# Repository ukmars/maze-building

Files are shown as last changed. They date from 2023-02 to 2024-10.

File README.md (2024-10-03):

# Building Mazes for Micromouse

For now this repository concerns itself only with the building of a maze for the classic micromouse contest. At some point this will be extended to the half-size contest.

Drawings and STL files for the maze base are in the [resources](./resources/) folder

Drawings and STL files for the walls and posts are in the [walls-and-posts](./walls-and-posts/) folder

These notes are divided into (not very well organised) sections:

- [Goals](./010-Goals.md)
- [Materials](./050-Materials.md)
- [Design](./060-Design.md)
- [Construction](./070-Construction.md)
- [Walls and Posts](./080-Walls-And-Posts.md)
- [Costs](./090-Costs.md)

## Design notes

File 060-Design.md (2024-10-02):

# Design outline

After a lot of deliberation, we settled on a maze constructed from 540mm tiles. Each tile is made from two layers with interlocking tabs to ensure better vertical alignment.

### 540mm Tiles
Increasing the size of the tiless to 540mm x 540mm would mean that 36 tiles are needed to build a full maze although these dimensions are outside the capacity of typical home CNC machines like laser cutters. Tiles this size will fit even in small cars and should be small enough to fit on a car seat and would be small enough to fit within the floor footprint of something like a washing machine. The tiling of these larger pieces allows for a good border around the maze area and no special parts for the outer perimeter walls. The existing UK maze is effectively made up from panels of four 540mm tiles.

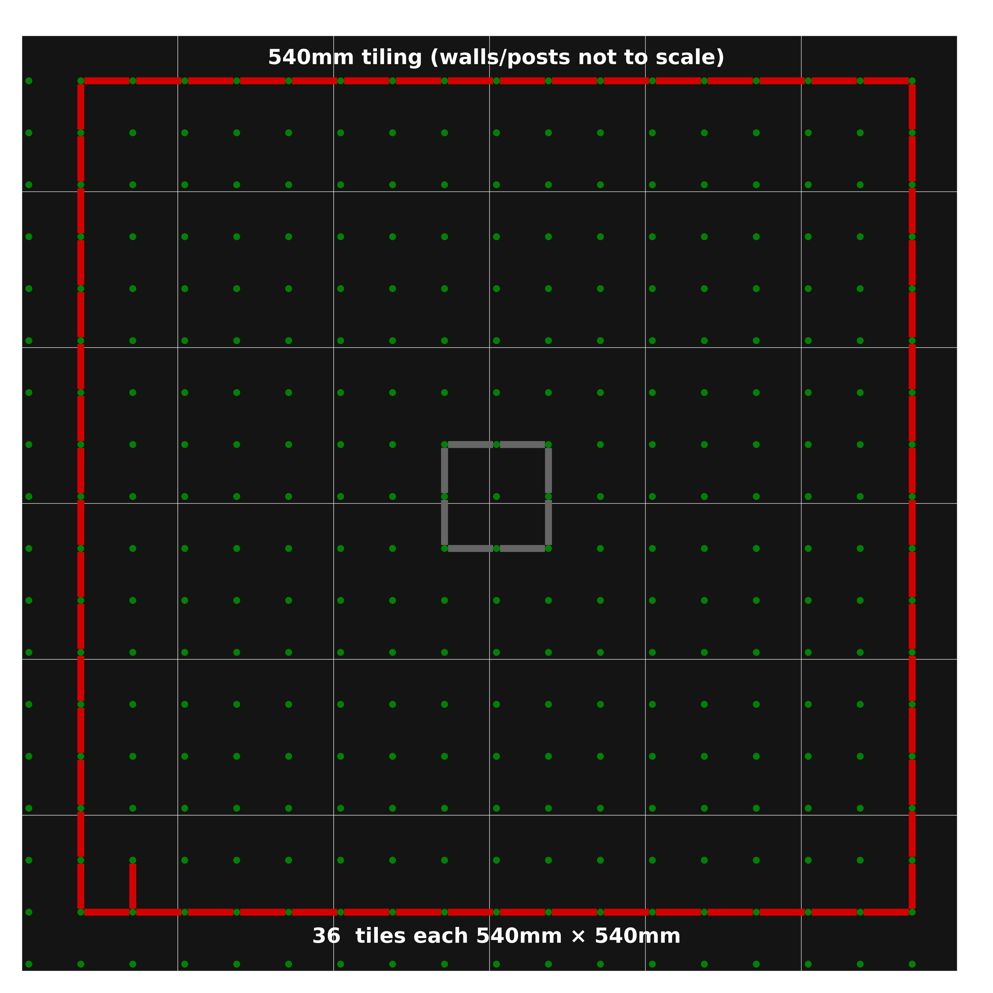
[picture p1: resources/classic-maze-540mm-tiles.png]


The area available is larger than needed for a standard 16x16 maze. The additional space could be used to construct practice areas for sensor calibration.

## Layered Tiles

Regardless of the size of individual tiles they must be joined together somehow. The joins must keep the tiles located both horizontally and vertically with a high degree of accuracy. the published rules permit quite large gaps and steps. This is mostly to remind builders of the worst case. High performance mice are much more sensitive than their forebears from the 1980s and are only really able to shine on a high-quality maze. Thus, a contest maze should be as close to seamless and stepless as possible.

After some experimentation, the final design used in 2023 is a two-layer tabbed tile of 540mmx540mm. Rather than separate tabs, the bottom layer is machined from a single piece to create the interlocking tabs and voids. This view shows a set of four tiles assembled into a panel:

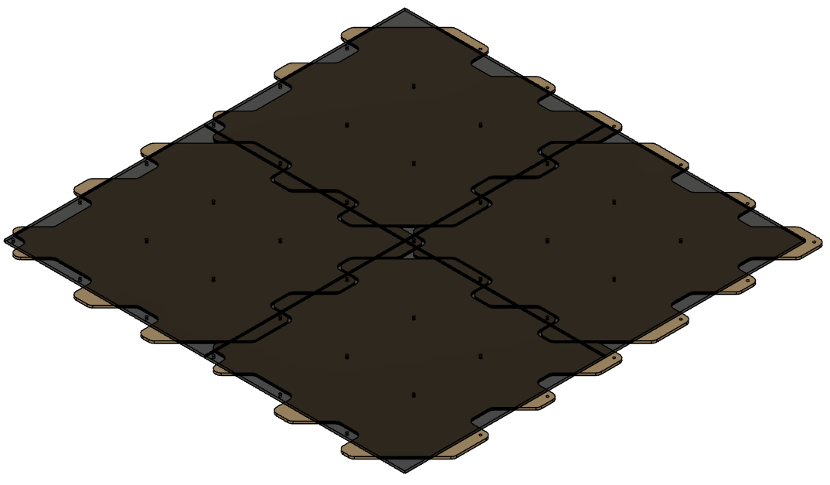
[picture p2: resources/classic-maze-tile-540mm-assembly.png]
540mm-tabbed-assembly


Each tile looks like this and is made of two separate layers aligned by the post holes then glued and pinned together.
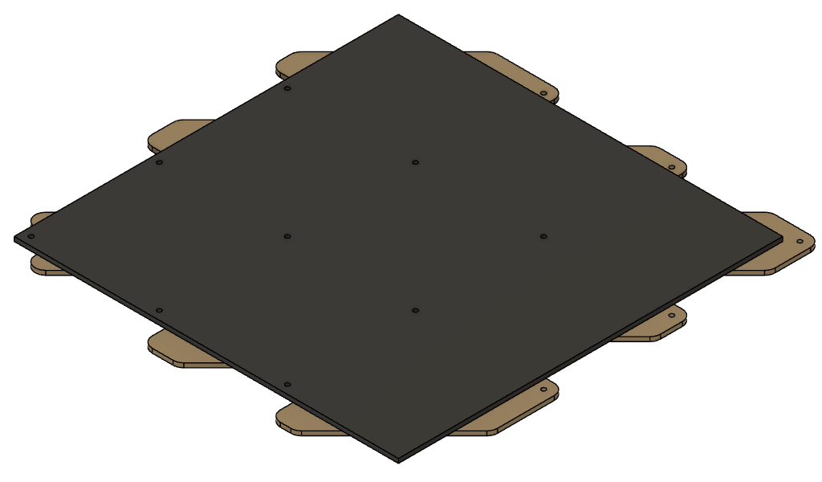
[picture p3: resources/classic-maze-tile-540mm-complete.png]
540mm individual tile


There is a video showing how these are made and assembled:

https://www.youtube.com/watch?v=BzY3Bj1GRg4

## Manufacture

Individual  files showing the component design can be found in the [resources](./resources/) directory. There are images of each part and a PDF file with the dimensions. You will also find DXF and SVG files with the outlines and hole positons. Dimensions are in mm.

The raw material is 6mm MDF. We use self-coloured black MDF but you can use whatever is available and paint it to suit. It is easier to pre-paint the top layer before cutting to avoid having to clean up the holes and edges afterwards.

Holes are nominally 6.1mm and can be adjusted to suit your particular posts.

Cutting the top layer should be done such that it is about 0.25mm undersize to allow for small innaccuracies in the alignment while not creating an excessive gap.

## Edges

In an assembled maze, there will be a row of post holes along two edges that are slightly difficult to use. To make that easier, I have pieces made from two layers of 3mm MDF, cut on a lser. They join together to make a strip like this:

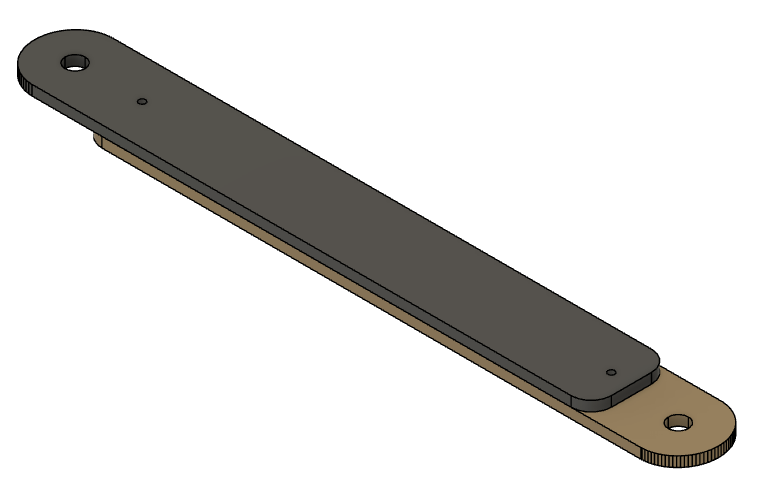
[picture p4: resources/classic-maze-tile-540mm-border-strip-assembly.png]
edge strip


And they can be placed around the edge like this:

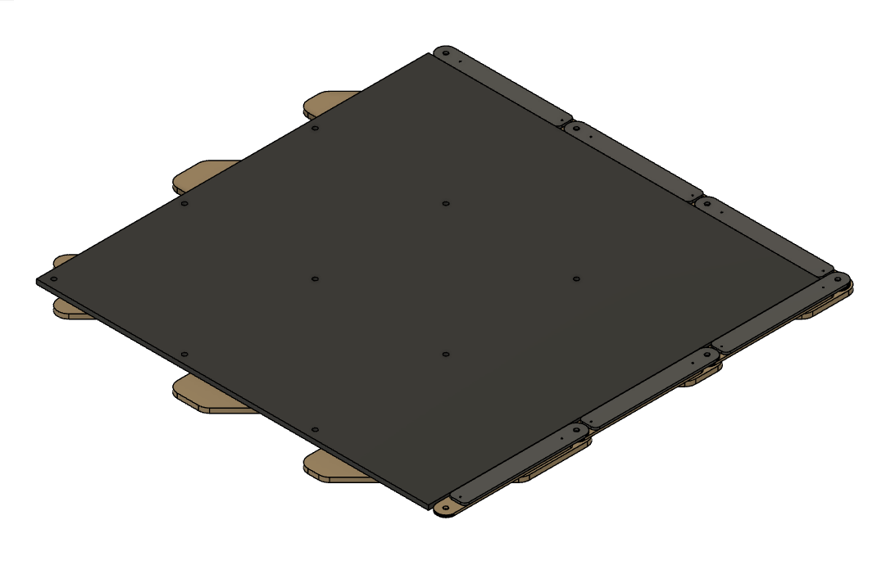
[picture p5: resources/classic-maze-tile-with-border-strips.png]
maze with strips


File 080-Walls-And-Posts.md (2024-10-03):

# Maze Walls and posts

## Walls

Although walls can be 3D printed, the UKMARS contest walls are all made from MDF. Suitable blanks are constructed and then covered with self-adhesive vinyl. The red top is created by adding red masking tape. These materials adhere well enough for contest use and provide a uniform and repeatable surface for sensor calibration.

Each wall has tabs at either end to locate in slots in the posts. Tabs are made from 2mm plywood and glued into slots cut in the wall ends. Any common wood glue will be fine. Do not use the dark brown Gorilla Glue as it expands while curing. The tabs are symmetric to make it easy to insert a wall either way up. With a different bottom surface, walls can easily be inverted to mark off special sections or temporary walls. This is particularly useful when creating a wall-follower maze that is then converted to a normal maze-solver version.

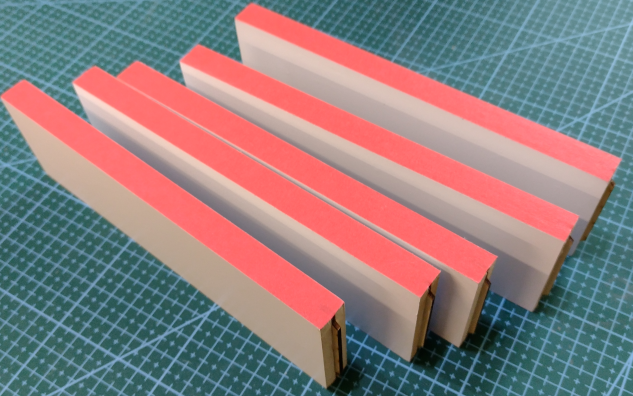
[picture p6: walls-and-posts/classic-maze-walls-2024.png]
Classic Walls


It is possible to make 3D printed walls with an FDM printer. Simply printing the STL file however will be pretty slow. A better solution is modify the slicer settings to use only two outer wall loops, 3 or 4 bottom layers, no top layers and no infill. You can use a relatively large layer height of 0.24mm or more. This creates a hollow wall that can be filled with two pieces of 5mm foamboard for a lightweight and strong wall. The wall should be covered with white self-adhesive vinyl in the same way that the MDF walls are. It may be necessary to add glue to the inside of the walls to prevent them from bowing out around the foamboard filler. Most common glue types will be fine. Hold the walls together while it sets. Do not use the dark brown Gorilla Glue as it expands while curing. 

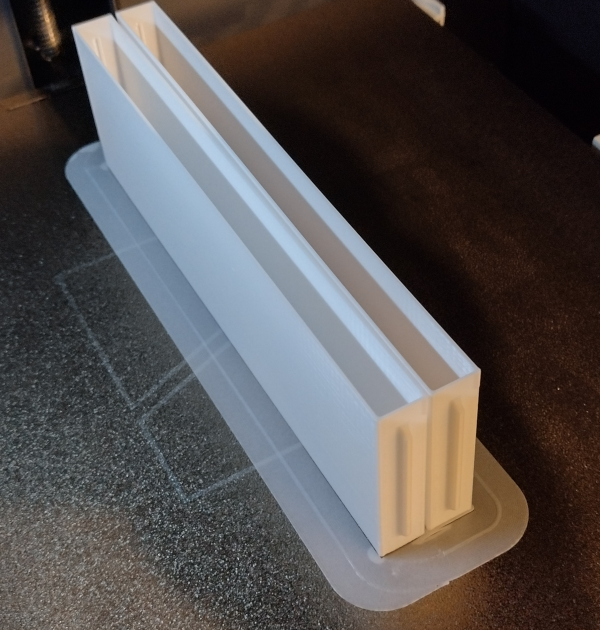
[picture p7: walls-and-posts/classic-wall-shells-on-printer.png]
Classic Wall Shelld and Filled

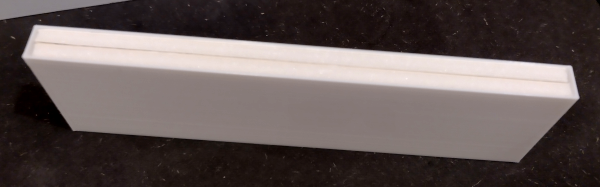
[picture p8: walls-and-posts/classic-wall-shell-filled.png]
Classic Wall Shelled


If you have a fancy multi-filament printer, you can even print the bottom two layers with a red filament.

In the [walls-and-posts](walls-and-posts) folder, there is a .3mf file showing how to set up the slicing.

Note that the walls are a little under the 168mm available between posts. That should ensure some tolerance in manufature. If you make walls, be sure they are no longer than 168mm or there will be problems with the fit.

For a full contest maze there will be a need for some 300 each posts and walls.

The covering material is Ri-Mark Event M300 Matt White Vinyl and is available from many sources. A 5M x 310mm roll would cost about £10 and is enough for about 60 walls.

## Resources
Drawings, descriptions and STL files are available in the [walls-and-posts](walls-and-posts) folder.

## Posts

Maze posts must have slots that provide an easy sliding fit for the tabs on the ends of the walls. The design files here show a post that is 11.5mm square - slightly less than the nominal 12mm square. Like the walls, this provides for some small variation in manufacture ad maze hole positioning. These are quite tight tolerances. If you make yuour own posts, run tests until you are sure you have the sizing correct. It is common for exposure times to affect the finished dimensions of resin prints and the slicer settings will affect the finished size of FDM prints. 

The peg that locates the post, and aligns the maze base parts is nominally 6mm diameter and long enough to fit through two 6mm layers. the peg is shown at less than 6mm in the notes and drawing because misalignment of FDM printed parts will inevitably make the peg seem too tight. Some filing or sanding may be needed to get a good fit. No real harm is done if the posts are a little loose but you will soon tire of having the post pull out whenever you remove a wall.

Posts are relatively hard to make without a 3D printer of some kind. Resin printers are fast (perhaps 30 posts in 2 hours) but the material is brittle. FDM printers are slow (perhaps 8 posts in 4 hours) but the result is much tougher.

There are two post designs in [walls-and-posts](walls-and-posts)

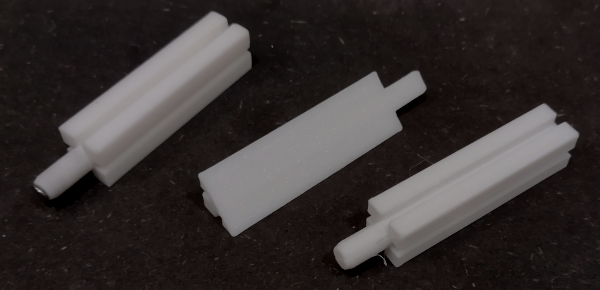
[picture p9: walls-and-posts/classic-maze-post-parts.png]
Classic Post Parts


### Resin printing
For resin printed posts the design incorporates a slightly shorter post with a hole through the centre to accept a 25mmx2mm nail. Nails are glued in to the hole and provide significant reinforcement. Even if a post breaks in the maze, it will be easy to extract the stub. The nails are cheap and readily available. Use an ABS-like white resin. It probably does not matter too much which brand and reflectifity of the posts is not normally a great problem.

### FDM printing
Attemmpting to print the post with an FDM printer as a single piece is doomed. The layers are not strongly bonded and you will get a weak post. The design here prints each post in two halves that are simply glued together to make a full post. Simple superglue is fine but arguably the best choice is the kind og glue sold as 'mitre adhesive' It is quite thick and has a very low odour. Normally it is supplied with a can of accelerant. You can appluy the glue to one half and accelerant to the other. Take care as the accelerant makes it set up almost immediately. I find it better to spray a bit of accelerant on a cloth then wipe the non-glued post half on that to transfer just enough to speed up the setting. The best choice of filament is probably white PETG for toughness and no fumes. However, PLA is cheaper and faster to print. Filament pigmentation can vary greatly. I just use cheap white Geeetech PLA. Many others will work just fine.

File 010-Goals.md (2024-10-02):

# Goals

- create a portable maze for classic micromouse contests
- use multiple identical tiles or panels (a panel is a maze section comprised of one or more tiles)
- limit panel size to no more than 750mm x 750mm
- design for distributed manufacture
- permits full 16x16 maze layout
- panels should be self-aligning vertically and positively located horizontally
- costs should be a significant factor in any choices

To get the question of cost addressed quickly, I estimate that even with economic materials, it may cost something like £45-50 per square meter to build a classic maze which amounts to £350-400 for the whole maze. This is for raw materials only. And relatively cheap ones at that. 

#### Traditional designs

The common approach for a classic micromouse maze is nine sections of around 1m² size. These are typically not all the same design and so must be fitted together in a particular fashion. These sections are large and heavy and do not fit in many family cars. The contest mazes in Japan and Taiwan and the APEC maze are made like this.

#### Tiles and Panels

For a new maze building project UKMARS have used a more flexible design that uses smaller panels. Those panels are large enough that fitting them together is not overly time consuming and yet small enough for easy transport in almost any domestic motor car. Individual panels are light yet durable since they are likely to be poorly handled during transport and storage. All the panels are identical so that they may be assembled with little complication and so that sub-sets may be assembled into custom layouts for special purposes and practice sessions.

#### Distributed Storage

Since the storage and transport of a maze by a single individual or organisation represents a single point of failure, we have made it possible for several members to hold a number of panels so that there is the best possible chance of a complete maze being available at any event. In the worst case, a smaller maze could still be assembled using however many panels are available on the day.

There are currently 6 maze holders, each having ten tiles. Four individuals are needed to make a standard maze and even if only three turn up, a 'legal' classic maze can still be constructed. The 'spare' sections would make an excellent practice maze.

#### Distributed Manufacture

For consistency, all maze tiles were manufactured together on the same CNC machine. Further efforts are underway to help others make dimensionally accurate, compatible tiles without the need for sohisticated machinery.

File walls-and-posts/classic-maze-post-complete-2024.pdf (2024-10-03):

Dept. Technical reference Created by Approved by Title DWG No. Document type Document status Rev. Date of issue Sheet 26/09/2024 1/1 Peter Harrison walls between them 12mm across or there will be problems fitting the The main part of the posts must not be more than the fit will be poor. 6mm and should not be much less than 5.9mm or test posts. The peg diameter must not exceed depend in part on the exposure time. Print some The finished size of your resin printed post will diameter. across the faces and have pegs that are 5.95mm These posts are nominally 11.5mm nominally DIMENSIONS enough to extract from the base. hand. Even if you break the post, it should be easy Glue the nail in with CA glue or whatever comes to the walls. elephant's foot issue whicc can cause interference with The chamfer at the top should help prevent the the hole before final curing. resin to drain out during printing. Be sure to clean out A pair of cross-holes near the top of the post allows nail shaft diameter is about 2mm. nails are very inexpensive. Try some to make surethe is a little shorter to make up for the nail head. These through the peg to accept a common 2mm nail. The peg Since resin prints are fragile, this design has a hole A complete post can be resin 3D printed in one piece. RESIN PRINTED 2.4 2.78

11.5

5.95 50 10.5

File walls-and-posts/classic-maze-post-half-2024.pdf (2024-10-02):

Dept. | Technical reference | Created by | Approved by Document type | Document status Title | DWG No. Rev. | Date of issue | Sheet 26/09/2024 | 1/1 Peter Harrison ⁵⁰ | 11

R2.9

2.75

2.4 MANUFACTURE Posts are typically 3D printed in half pieces. ABS or PETG is preferred for its strength. PLA will work but is more brittle. With a 0.4mm nozzle, on a Bambu P1S, each complete post will take about 8-9 minutes with a 0.24mm layer height. Use 6 walls loops to get a solid post. Fewer for a faster print. DIMENSIONS Each piece is one half of a post with the overall outer dimension set to 11.5mm Test your assembled parts. They must finish at less than 12mm across the flats to ensure that tolerances are met. The peg is shown at 5.8mm diameter. This is less than the nominal 6mm but it turns out to be hard to get perfect alignment when gluing the parts together. Also, your slicer settings and layer height will affect the finshed overall diameter and fit. Make test prints. There is a slight chamfer on the corners to help mitigate the tendency for some printers to produce a bulge at corners. ASSEMBLY Glue two pieces together to make one post. If you use a fast-setting adhesive like CyanoAcrylate, you may find they bond very quickly. It may take a bit of practice to get the alignment correct quickly enough. Some plastics like PETG do not seem to make CA glue cure very quickly. Use a medium thickness CA glue. The type sold in DIY stores as Mitre Adhesive works well. If you use an accelerator, it will greatly speed up the process. For ABS, you can try solvent adhesives which are more forgiving but may require the parts to be held together for some time whyile the glue set up. Consider a grid of 6mm holes in a piece of scrap material 1.5

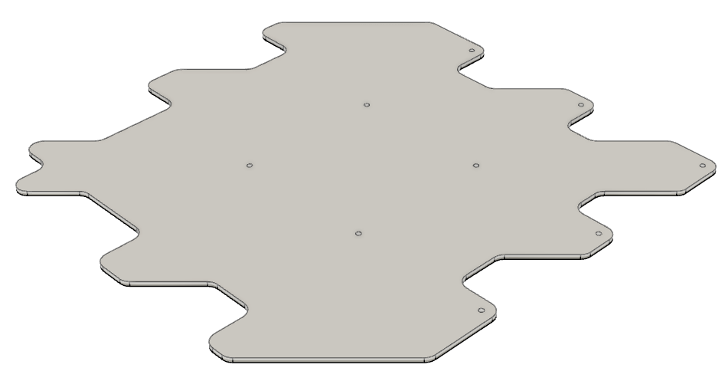
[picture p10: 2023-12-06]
resources/classic-maze-tile-540mm-bottom-layer.png

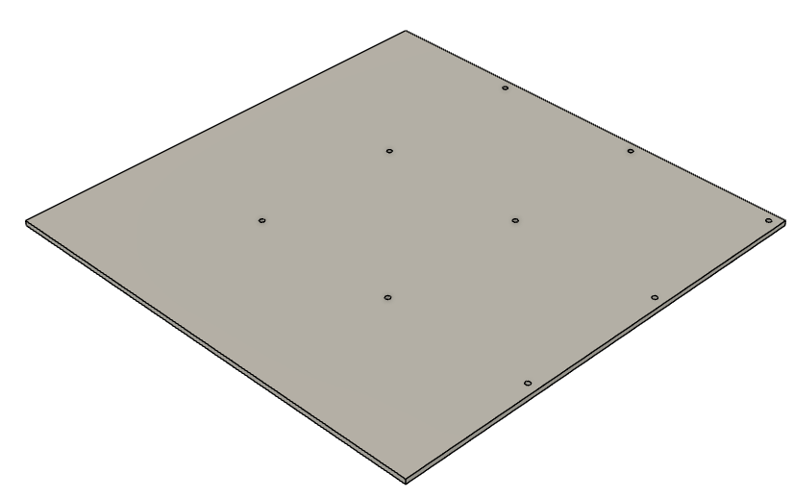
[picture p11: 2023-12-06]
resources/classic-maze-tile-540mm-top-layer.png

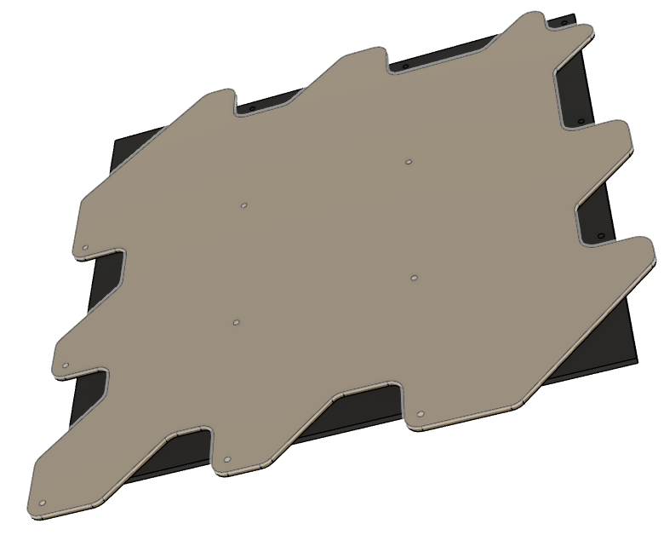
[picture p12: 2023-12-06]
resources/classic-maze-tile-540mm-below.png

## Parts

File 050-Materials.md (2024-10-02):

# Materials

For the current contest maze, UKMARS is using the black-dyed MDF sheet from Kitronic. 

---

For future reference though, here is a brief consideration of some other material choices.

Practically speaking there are few choices of material for the base (prices have been taken from a single supplier and so are only a relative guide, not absolute). Note that layered designs are not absolutely required to use the same material for all layers though there is some risk of differential expansion.

- **Plywood**. Typically 5.5mm thick and avaialble usually with a very thin hardwood veneer. This is lighter than MDF and more resistant to moisture and impact on fine edges. It is also perhaps less likely to be flat across a whole sheet. Varies a lot by supplier, Relatively cheap hardwood external grade stuff is common. Guide prices around £25/sheet. High quality Marine plywood in 6mm is likely to be £80/sheet and 6mm Birch plywood is about £76/sheet. **Unless a known quality, named brand with guaranteed thickness can be found, plywood is probably not a safe choice for the top surface of the maze.**
<br>

- **MDF**. Quality varies widely from very poor to very good. Moisture resistant varieties are better but not moisture proof. All MDF, including Medite should be sealed. MDF is about 20-25% more dense than plywood. Typically 6mm thick. MR is about £25/sheet. **Because of the variability, generic MDF is not considered as a candidate in these notes.**
<br>  

- **Medite**. This is a high grade MDF, but much better than the stuff from your local DIY Store. Most importantly, it is a known quality not subject to the vagaries of your local builders merchant. It is probably what you (should) buy when looking for MDF for a laser cutter.If you want MDF, choose Medite. Also avaliable in 3mm and 4mm thicknesses. 6mm thickness about £28/sheet. MR variety £33/sheet.
For more details see [Medite MDF](./materials/053-Medite-MDF.md) in the [Materials](./materials/) directory
<br>  

- **Valchromat** is the most widely available dyed MDF. Its properties are similar to MDF but the fibres are dyed before manufacture producing a consistent colour throughout the sheet. The thinnest sheets of Valchromat are 8mm which makes it good for a top layer but too thick for a three-layer design on all three layers. Surface properties are similar to Medite but it is possible to use it without any further paint of finish. A surface sealer might be wise though. Valchromat if _very_ expensive though and starts at £100 per sheet. 
For more details about various black MDF types look at [Black MDF](./materials/057-Black-MDF.md) in the [Materials](./materials/) directory.
<br>  

- **Kitronic Dyed MDF** is a product that is dyed black throughout, very durable and availale in cut panels at a significantly better price than Valchromat. Cutting tests are needed for suitability with common laser cutters. The surface is very good and has high absorbtion of IR light.
For more details about the Kitronic material see [Kitronic Black MDF](./materials/058-Kitronic-Black-MDF.md) in the [Materials](./materials/) directory.

## Stability
Note that, in general, plywood is more stable in the long term than MDF and unlikely to suffer lasting damage from excess moisture.

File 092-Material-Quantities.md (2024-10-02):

# Material quantities

## Two layer, 540mm tiled Base

Needs 2x36 = 72 tile pieces.

Blanks would be 600mm square.

Cut from a single sheet of 1220x2440 material, there will be only 8 pieces possible.

That would require 9 sheets of raw material to make the 72 pieces to be cut into tiles.

## Walls using 12mm MDF sheet

Careful cutting permits 320 walls to be cut from one sheet of 12mm x 1220mm x 2440mm material using a thin blade saw (2mm kerf).

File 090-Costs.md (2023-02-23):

# Costs

**Look at the individual materials for costs. This is just a set of notes for now**

6mm black mdf top + 2×6mm medite approx £580
That is using 320mm tiles and Kitronic black MDF with kitronic 600x400x6mm medite
so 64 × £4.20 + 128 × £2.40 = £576

3 × 6mm medite approx £400
If using Kitronic sheets 600x400x3 => 192 x £2.40 = £460. Very wasteful. Kitronic 600x400 sheets represent 50% waste

1x6mm + 1x12mm medite approx £320

6mm black mdf + 12mm medite Approx £256 + £130 = £400

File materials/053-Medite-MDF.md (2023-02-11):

# Medite MDF

Medite is a tradename for a specific brand of Medium Density Fibreboard. Do not confuse this with the poor quality MDF you may have seen in your local DIY store or builder's merchant - though they may be able to supply it if asked.. This is a high quality material with excellent properties. Of particular importance is that by selecting a named brand (Medite Premier), there is some assurance that the thickness will be consistent regardless of where it is actually purchased. I believe the thickness tolerance is ±0.15mm.

While not moisture resistant, Medite Premium machines well and is suitable for use with a laser cutter.

Medite is widely available. One of the better-priced suppliers of full sheets and cut pieces is [Woodshop Direct](https://www.woodshopdirect.co.uk/plain-mdf-sheeting/medite-mdf-premier-sheet/). Their cut sheets are not suitable for direct use as maze tiles since they only specify an accuracy of ±1mm.

A well known supplier of materials for maker is [Kitronic](https://kitronik.co.uk/collections/mdf). they sell cut sheets generally sized to fit common laser cutters and CNC machines. Their sizes are not always obviously convenient but they do offer good prices and excellent service. There is no inear tolerance given for theirpanels

## Woodshop Direct
(cut size is ±1mm)

### Full sheet
6mm £28.40 inc VAT
12mm £43.80 inc VAT

A sheet gets 18 pieces at 400x400 => 6mm tiles are £1.60 ea, 12mm tiles are £2.44 ea
A sheet gets 8 pieces at 600x600 => 6mm tiles are £3.55 ea, 12mm tiles are £5.49 ea

### Cut pieces (in quantities of 100)
6mm Medite cut 370x370 £1.95 ea inc. Thus a complete maze layer of 64 pieces would cost £125
12mm Medite cut 370x370, £2.68 ea. inc. Thus a full maze layer of 64 pieces would cost £172

6mm Medite cut 400x400 £2.05 ea inc. A complete maze layer of 64 pieces would cost £131
6mm Medite cut 600x400 £2.95 ea inc. A complete maze layer of 64 pieces would cost £189
6mm Medite cut 600x600 £3.97 ea inc. A complete maze layer of 64 pieces would cost £143

12mm Medite cut 400x400, £2.89 ea. inc. Thus a complete maze layer of 36 pieces would cost £185
12mm Medite cut 600x600, £5.89 ea. inc. Thus a complete maze layer of 36 pieces would cost £212

## Kitronic
6mm medite 600mmx400mm £2.64 ea inc, (10-99 off). A complete maze layer of 64 pieces would cost £169.

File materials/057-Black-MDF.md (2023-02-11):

# Black MDF

Only cut sheets are considered.

## Kitronic
[Kitronic laserable 6mm black MDF 600x400](https://kitronik.co.uk/collections/mdf/products/32161-6mm-laser-compatible-black-mdf-600mm-x-400mm-sheet) 
£4.20 inc each, for 10-99 pieces. For the 64 pieces needed to cover a maze that would be £269

Note that it is possible to construct a 360×360 tile _and_ its tabs/supports from a single 600×400 piece of raw material. This would make for a complete maze that does not need any further finishing.

For a special order of at least 100 pieces, Kitronic have quoted a price of £6.24 inc for pieces at 600mm x 600mm. To make one maze layer would require 36 of these at a total cost of £225. Not all the tabs/supports can be made from that size but a small amount of additional plain Medite would make the total cost comparable to the use of a 360×360 base tile.

Kitronic alo sell a laserable 3mm black painted MDF 600mm x 400mm for £1.86, inc each at qty 100. That is about £120 to cover a maze but is too thin for any use except as a skin on the top surface.

## Valchromat
For comparison only - because of the cost - some eample pricing of 8mm Valchromat :

## Cutsmart.co.uk
Full sheet black valchromat, 8mm thick £123 inc VAT
Full sheet black valchromat, 12mm thick, £168 in VAT

## atlantictimber.co.uk
Full sheet black valchromat, 8mm thick £99 inc VAT
Full sheet black valchromat, 12mm thick, £135 in VAT

## mdfdirect.co.uk
Black Valchromat cut to 360x360, 8mm thick, £9.28 ea (£109 full sheet)
Black Valchromat cut to 360x360, 12mm thick, £11.39 ea (£149 full sheet)

Black Valchromat cut to 540x540, 8mm thick, £16.38 ea (£109 full sheet)
Black Valchromat cut to 540x540, 12mm thick, £21.12 ea (£149 full sheet)

## Hobarts
Black Fibramore, 3mm thick, 800x400 at £5.86 ea. More expensive than kitronic

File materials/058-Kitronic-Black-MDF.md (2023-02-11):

# Kitronic Black MDF

## Material

A big question remains on cuttability.

## 360mm Tiles

A single layer of 360mm tiles needs 64 pieces
Kitronic do black MDF at 600mmx400mm at £3.96 inc each in quantities of >= 100.

We would want to build 1½ or 2 mazes so 100 off pricing is good.

From a single 600x400 piece we can build a single 360mm tile with tabs and support. That would put the unit cost of a tile at £4 or £256 for a complete maze.

The same size Medite is just £2.40 making a similar design just £154. It would need paint.
(Kitronic, surprisingly, is the cheapest I can find for gut 6mm medite Premium)

A three-layer design in this tile size would use 192 pieces and waste 30% at a cost of £760.30

## 540mm tiles

A single layer of 540mmx540mm tiles needs 36 pieces.
For a special order of >= 100 pieces from Kitronic would work out at £6.24 inc each. For three layers, that would come to £674 for a maze using all black MDF. 

6mm Medite is available in 800mmx600mm pieces cosing £4.32 inc in 100-off quantities (presumably 600x600 would be available to special order) 

If two of the layers were Medite, the cost might reduce to 36×£6.24 + 72×£4.32 = £535.70. Less than that if the Medite can be had for a pro-rata price in 600mmx600mm (possibly about £460)

A single layer plus tabs solution in this size tile would use up two pieces per tile in order to provide adequate support. Thus the cost for a complete maze might be 2×36×£6.24 = £450 for all black. Using Medite for the tabs/supports would reduce the cost to 36×£6.24 + 36÷£4.32 = £380 if we threw away the waste or £345 if we could get 600mm square Medite prices pro-rata. (Or the builders payed cost for the waste :)

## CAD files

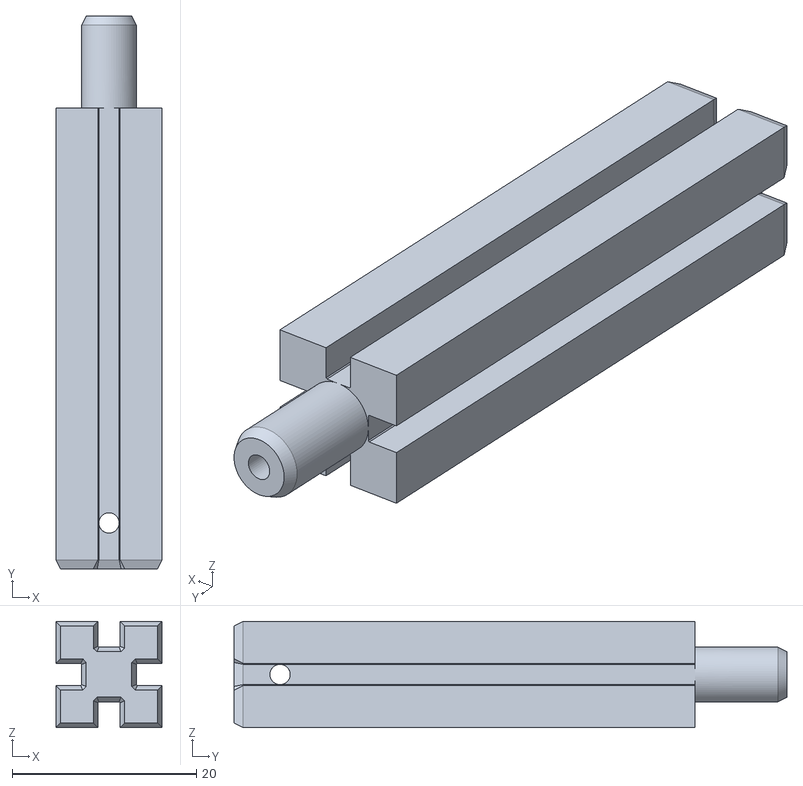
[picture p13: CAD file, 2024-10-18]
walls-and-posts/classic-maze-post-complete-2024.stl
11.5 x 60.0 x 11.5

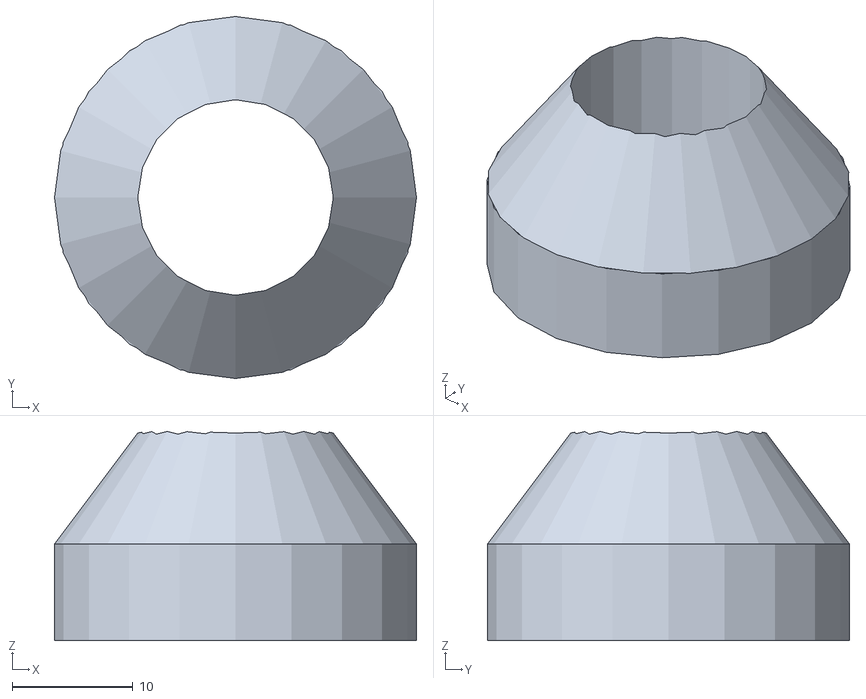
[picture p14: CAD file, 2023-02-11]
construction/drill-guide-holder.stl
30.0 x 30.0 x 17.3

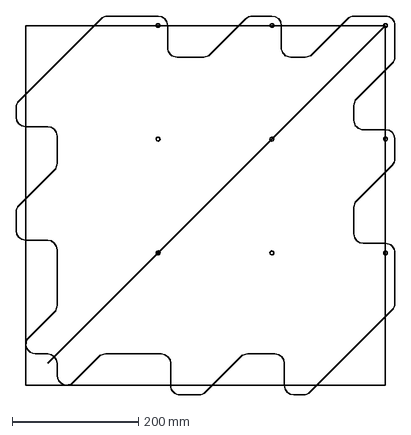
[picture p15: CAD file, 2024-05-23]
resources/UKMARS-maze-tile-540mm-bottom.dxf
600.0 x 600.0 mm

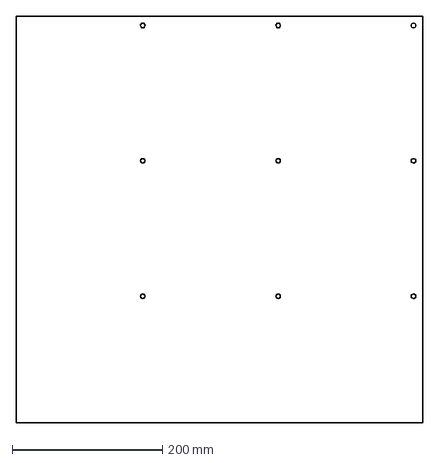
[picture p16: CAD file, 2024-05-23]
resources/UKMARS-maze-tile-540mm-top.dxf
540.0 x 540.0 mm

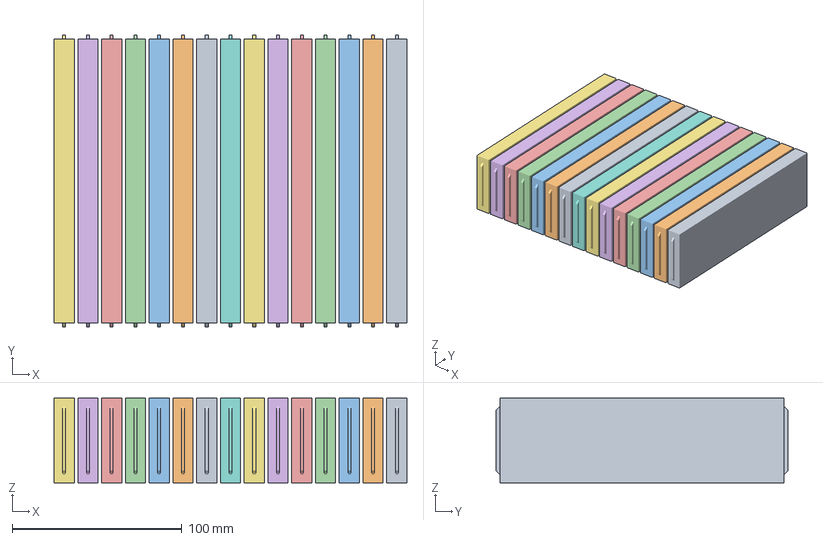
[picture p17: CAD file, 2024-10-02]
walls-and-posts/classic-maze-walls-shelled-x15.3mf
208.0 x 172.3 x 50.0 mm
classic-wall-2023-v6.stl(4)
classic-wall-2023-v6.stl(8)
classic-wall-2023-v6.stl(10)
classic-wall-2023-v6.stl(14)
classic-wall-2023-v6.stl(15)
classic-wall-2023-v6.stl
classic-wall-2023-v6.stl(1)
classic-wall-2023-v6.stl(2)
classic-wall-2023-v6.stl(3)
classic-wall-2023-v6.stl(5)
classic-wall-2023-v6.stl(6)
classic-wall-2023-v6.stl(7)
classic-wall-2023-v6.stl(9) x 3

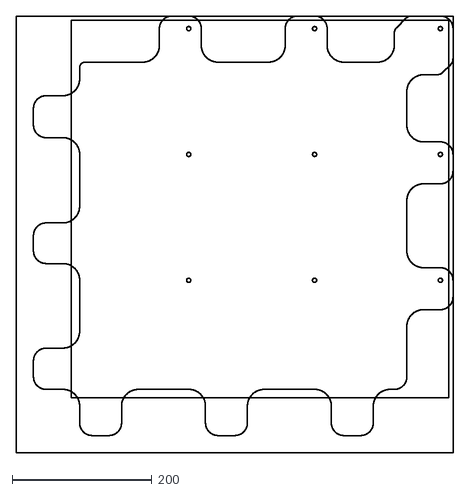
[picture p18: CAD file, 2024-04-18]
resources/classic-maze-tile-540mm-cut2d.dxf
625.0 x 625.0

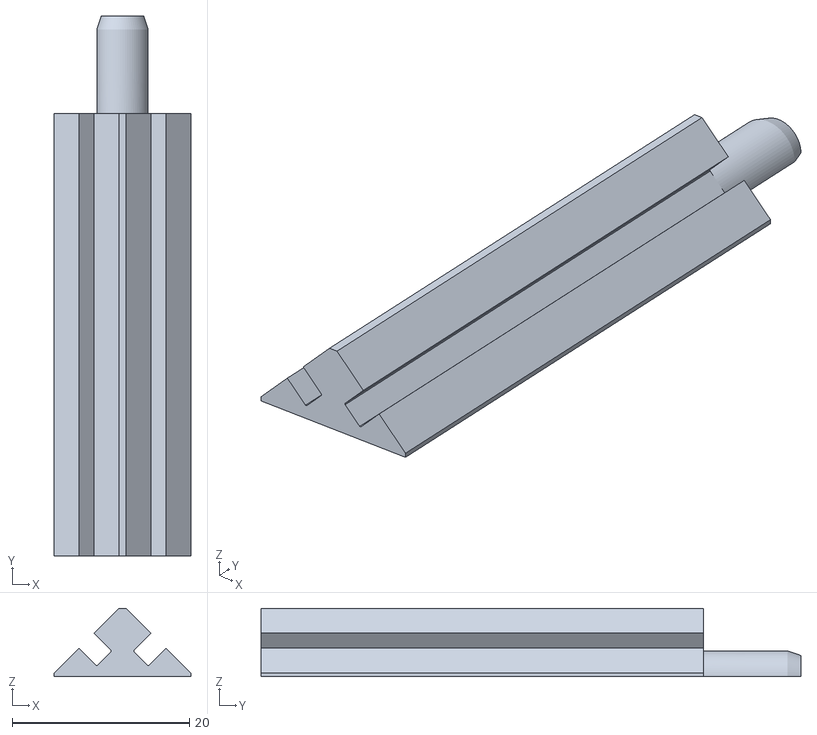
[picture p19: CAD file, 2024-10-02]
walls-and-posts/classic-maze-post-half-2024.stl
15.5 x 61.0 x 7.73

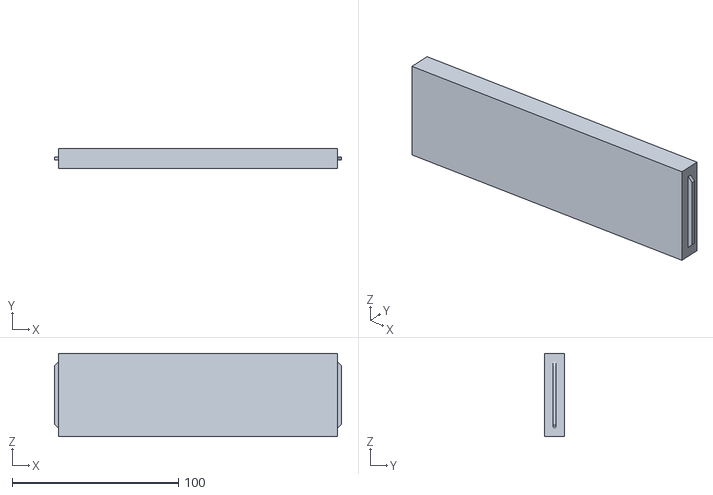
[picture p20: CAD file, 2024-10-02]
walls-and-posts/classic-maze-wall-printed-2024.stl
172.5 x 12.0 x 50.0

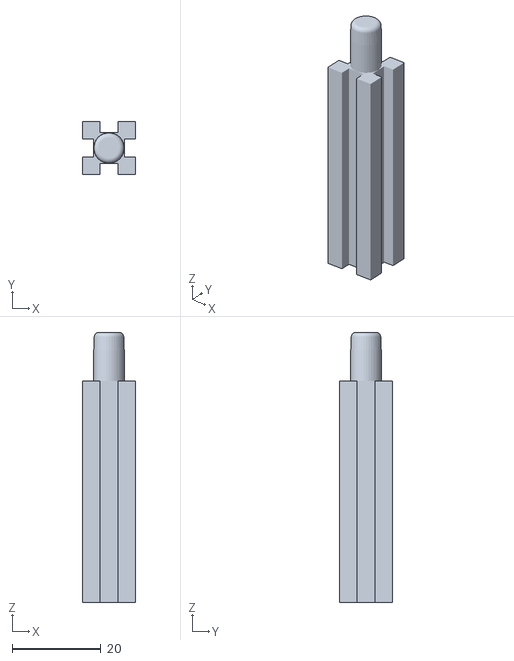
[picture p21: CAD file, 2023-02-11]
walls-and-posts/classic-maze-post.STL
12.0 x 12.0 x 61.0

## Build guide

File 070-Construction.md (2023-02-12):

# Construction

One of the project aims is to democratise manufacture. Not everyone would have the tools and/or skills needed to make a maze or maze components. Even so, we hope to make the overall construction options as wide as possible so that fully compatible maze parts are possible and distributed as widely as possible.

## Manufacture constraints

- Tile pieces must be cut accurately and square with minimal surface damage from tear-out.
- Edges should not be sharp but also not overly rounded to that joints are snug and fit without appreciable gaps.
- Allowance must be made for small variations in material thickness and dimensional changes due to differing storage environments
- Surface finish should be mandated using a widely available paint finish and method of application or by such other means as are available.

### Other considerations

With the relative popularity of CNC laser engraver/cutters and CNC routing machines, there are advantages in considering their use in the manufacture of maze tiles. Accuracy and repeatability are generally beyond doubt. However, thare are a couple of constraints surrounding their use.

- Not everyone has access so it it might be best to plan around the possibility of manufacture with other tools to avoid the burden falling on a small number of individuals.
- Even where such machines are available, they are likely to be limited in their working envelope. That can be made large enough but only at additional cost or by taking up large amounts of workshop space. In an ideal world, there would be ready access to machines with a working envelop of at least 600mm square or even 1000mm square. These currently can cost £2,500 or more so that is not likely to be a very viable option.
- Laser engravers are reasonably priced and widely available. However, diode lasers will take a relatively long time to cut out the parts needed and are constrained to a 400mm x 400mm working area. CO2 lasers are much faster but unlikely to be able to cut anything larger than 400mm x 600mm. Hobby class CO2 lasers are too restricted in working area to be very useful

#### Drilling Jig

To make it possible for people without access to CNC machines to make a maze, we have also considered the development of a drilling jig. The idea is that a builder would only need to be able to accurately cut squares of base material and then use a jig to drill the post holes with a cheap hand drill. Such a jig could be made by those who do have access to precision machinery and then distributed to anyone who needed it. A small number of jigs would serve the needs of many and could even turn out to be the best method overall. 

There are more details in the [Drilling Jigs](./construction/072-Drilling-Jigs.md) page in [Construction](./construction/)

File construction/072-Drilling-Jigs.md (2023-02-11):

# Drilling Jigs

If there is no access to a CNC macine such as a router or a laser cutter, then the post holes will have to be made by hand. For home use this is perfectly possible by careful measurement on individual tiles. If the tiles must join arbitrarily with other tiles then steps must be taken to make the hole location more accurate.

A drilling jig has two functions. One is to accurately locate the holes with respect to two reference edges on a tile piece and the other is to ensure that the holes are drilled perpendicular to the surface. Ideally, these two functions will be incorporated into a single jig but it is possible to create one jig to locate the holes and another to drill them.

### Drill bushes
Steel bushes or drill guides are readily available and these should be hardened if more than a few holes will be needed. These bushes are typically cylindrical with a bore just large enough to pass the drill bit through. Since the outer diameter may be only 20mm or so, they will need some additional support to help keep them perpendicular to the workpiece. 

If the bushes are to be used only for marking the hole positions they need only be positioned accurately on the jig. A pointed steel shaft that is a close fit in the bush can be used as a centre punch. Be sure that the point of the punch really is concentric with the shaft. 

### Bush Support for Drilling
A hefty hand-drill can easily exert quite a large force that will tend to tip a drill bush over. Longer bushes give greater accuracy but also more leverage. For consistent results the bushes can be mounted in thicker material but this can be ungainly in use. A better solution might be to provide local support for a wider base. A 3D-printed support collar is an easy solution.

### Edge Locating Guides
Locating the holes from the reference edges can be done with pins or guides on the jig. Guide pins should be substatial and a good choice would be steel pins the same diameter as the post holes so that they can also be used as gauges or for alignment of maze pieces during manufacture.

Just three pins are sufficient to accurately determine the location of the jig. Two pins touch against one edge and one agains hte other. The two pins on the same side should be as far apart as possible for the best accuracy. It is most convenient and flexible to allow for two pins on each edge. It is important hat these pins are perpendicular to the jig base and so they should also have wide collars to help ensure that.

While it is possible to use strips of material attached to the jig to locate the edges this can be to be less accurate and more error-prone if extra care is not taken. Such strips can easily trap debris such as sawdust and will then no longer seat accurately against the tile stock. This may not be apparent until the holes are later found not to line up correctly with adjacent tiles. If using strips take extra care to ensure they are clean and leave a gap at the corner where there is the greatest risk of debris collecting. 

### Drilling Individual Holes
Instead of buying a large number of drill guide bushes, just one can be usedIf the holes are to be drilled individually without a full jig once the positions have been accurately marked. To do this a single bush can be mounted in a holder that is large enough to keep it perpendicular to the surface. Something simple is easily made with a 3D printer:

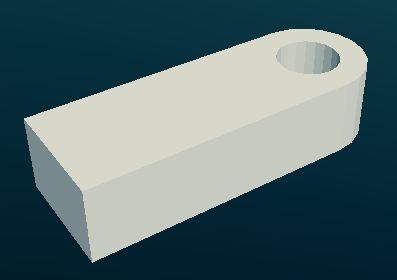
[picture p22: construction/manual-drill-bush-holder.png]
Manual Drill Bush Holder


### Accuracy
Accuracy and repeatability are key to the use of a drill jig. That will be a combination of an accuratly constructed jig and good drilling technique. While it is possible to make a jig by hand to arbitrary accuracy standards, it is much easier if the jig is at least laid out and cut using CNC machines. A CNC router or laser with a working area of 400mm×400mm will be needed. Fortunately, that is just within the capabilities of common diode laser engravers.

## TODO
- Drawings for a 4-hole and 9-hole jig
- assembly instructions for same

### Example
An example of a possible arrangement for a four-hole drilling jig looks like this:
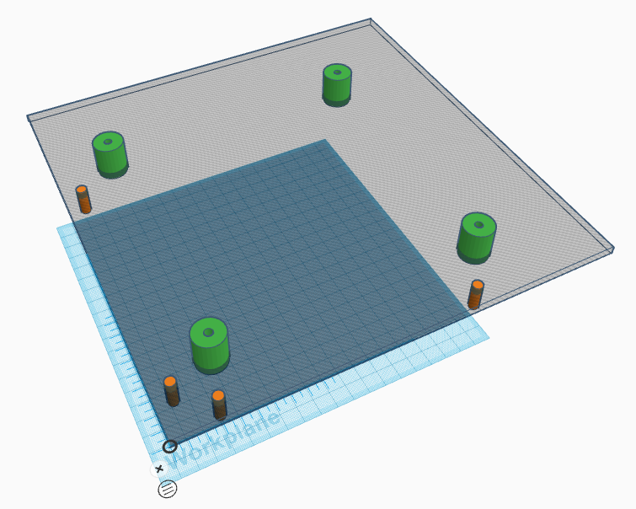
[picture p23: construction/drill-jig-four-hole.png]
Example Jig


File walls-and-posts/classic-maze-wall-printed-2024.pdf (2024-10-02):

Dept. | Technical reference | Created by | Approved by Document type | Document status Title | DWG No. Rev. | Date of issue | Sheet 26/09/2024 | 1/1 classic-wall-2024 Peter Harrison ¹⁶⁷.5

50

2 2.5

40 12 The classic maze wall can be imported to a slicer and printed from the solid. However, the printing of a complete wall is very time consuming and uses a lot of material. Also, the material used is unlikely to have surface properties similar to the vinyl covered contest walls. If you have a filament (FDM) printer, very serviceable walls can be produced quite quickly in batches by adjusting your slicer settings. Set up the slicer to have four bottom layers, only one outside wall, NO top walls and zero% infill. This will produce a completely hollow wall which can be filled with two pieces of 5mm foamboard and then covered with white sign-making vinyl exacly as is used on the contest walls. Do not try to use 'vase mode' as this will only allow you to print one wall at a time. The foam-core inserts are likely to need a drop of glue to prevent the sides from bowing out. so long as the outside is covered in vinyl, almost any filament type will do though I guess PETG will be stronger. Make sure the length does not exceed 167.5mm and watch out for bulging if the seam is at corner.

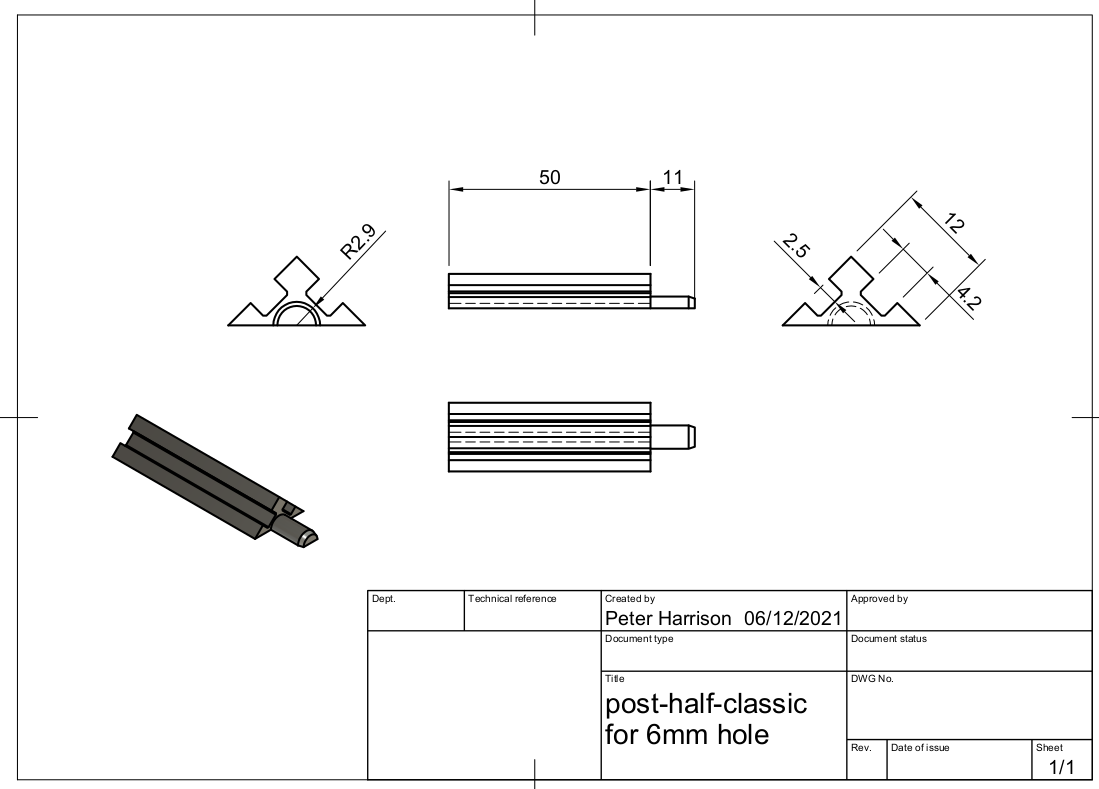
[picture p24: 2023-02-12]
walls-and-posts/maze-post-classic-3D-print.png

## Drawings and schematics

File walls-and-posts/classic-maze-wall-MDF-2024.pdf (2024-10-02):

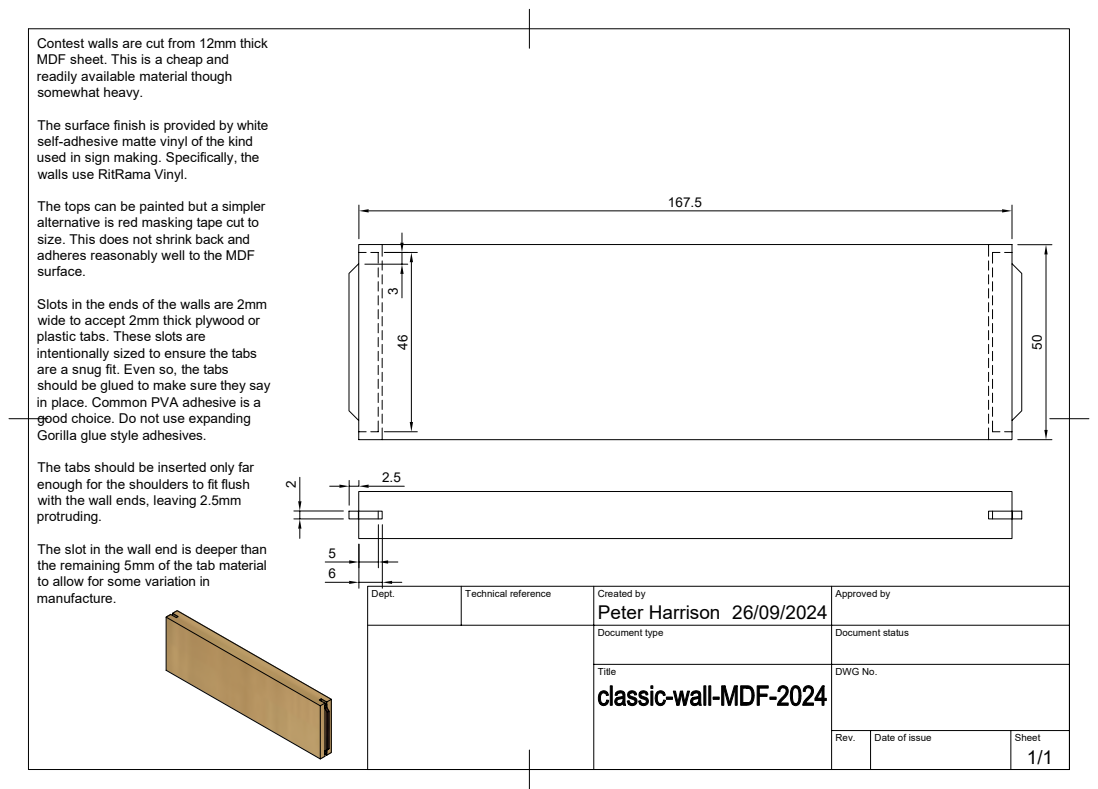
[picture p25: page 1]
Dept.; Technical reference; Created by; Approved by Document type; Document status Title; DWG No. Rev.; Date of issue; Sheet 26/09/2024; 1/1 Peter Harrison ¹⁶⁷.5

3 Contest walls are cut from 12mm thick MDF sheet. This is a cheap and readily available material though somewhat heavy. The surface finish is provided by white self-adhesive matte vinyl of the kind used in sign making. Specifically, the walls use RitRama Vinyl. The tops can be painted but a simpler alternative is red masking tape cut to size. This does not shrink back and adheres reasonably well to the MDF surface. Slots in the ends of the walls are 2mm wide to accept 2mm thick plywood or plastic tabs. These slots are intentionally sized to ensure the tabs are a snug fit. Even so, the tabs should be glued to make sure they say in place. Common PVA adhesive is a good choice. Do not use expanding Gorilla glue style adhesives. The tabs should be inserted only far enough for the shoulders to fit flush with the wall ends, leaving 2.5mm protruding. The slot in the wall end is deeper than the remaining 5mm of the tab material to allow for some variation in manufacture.

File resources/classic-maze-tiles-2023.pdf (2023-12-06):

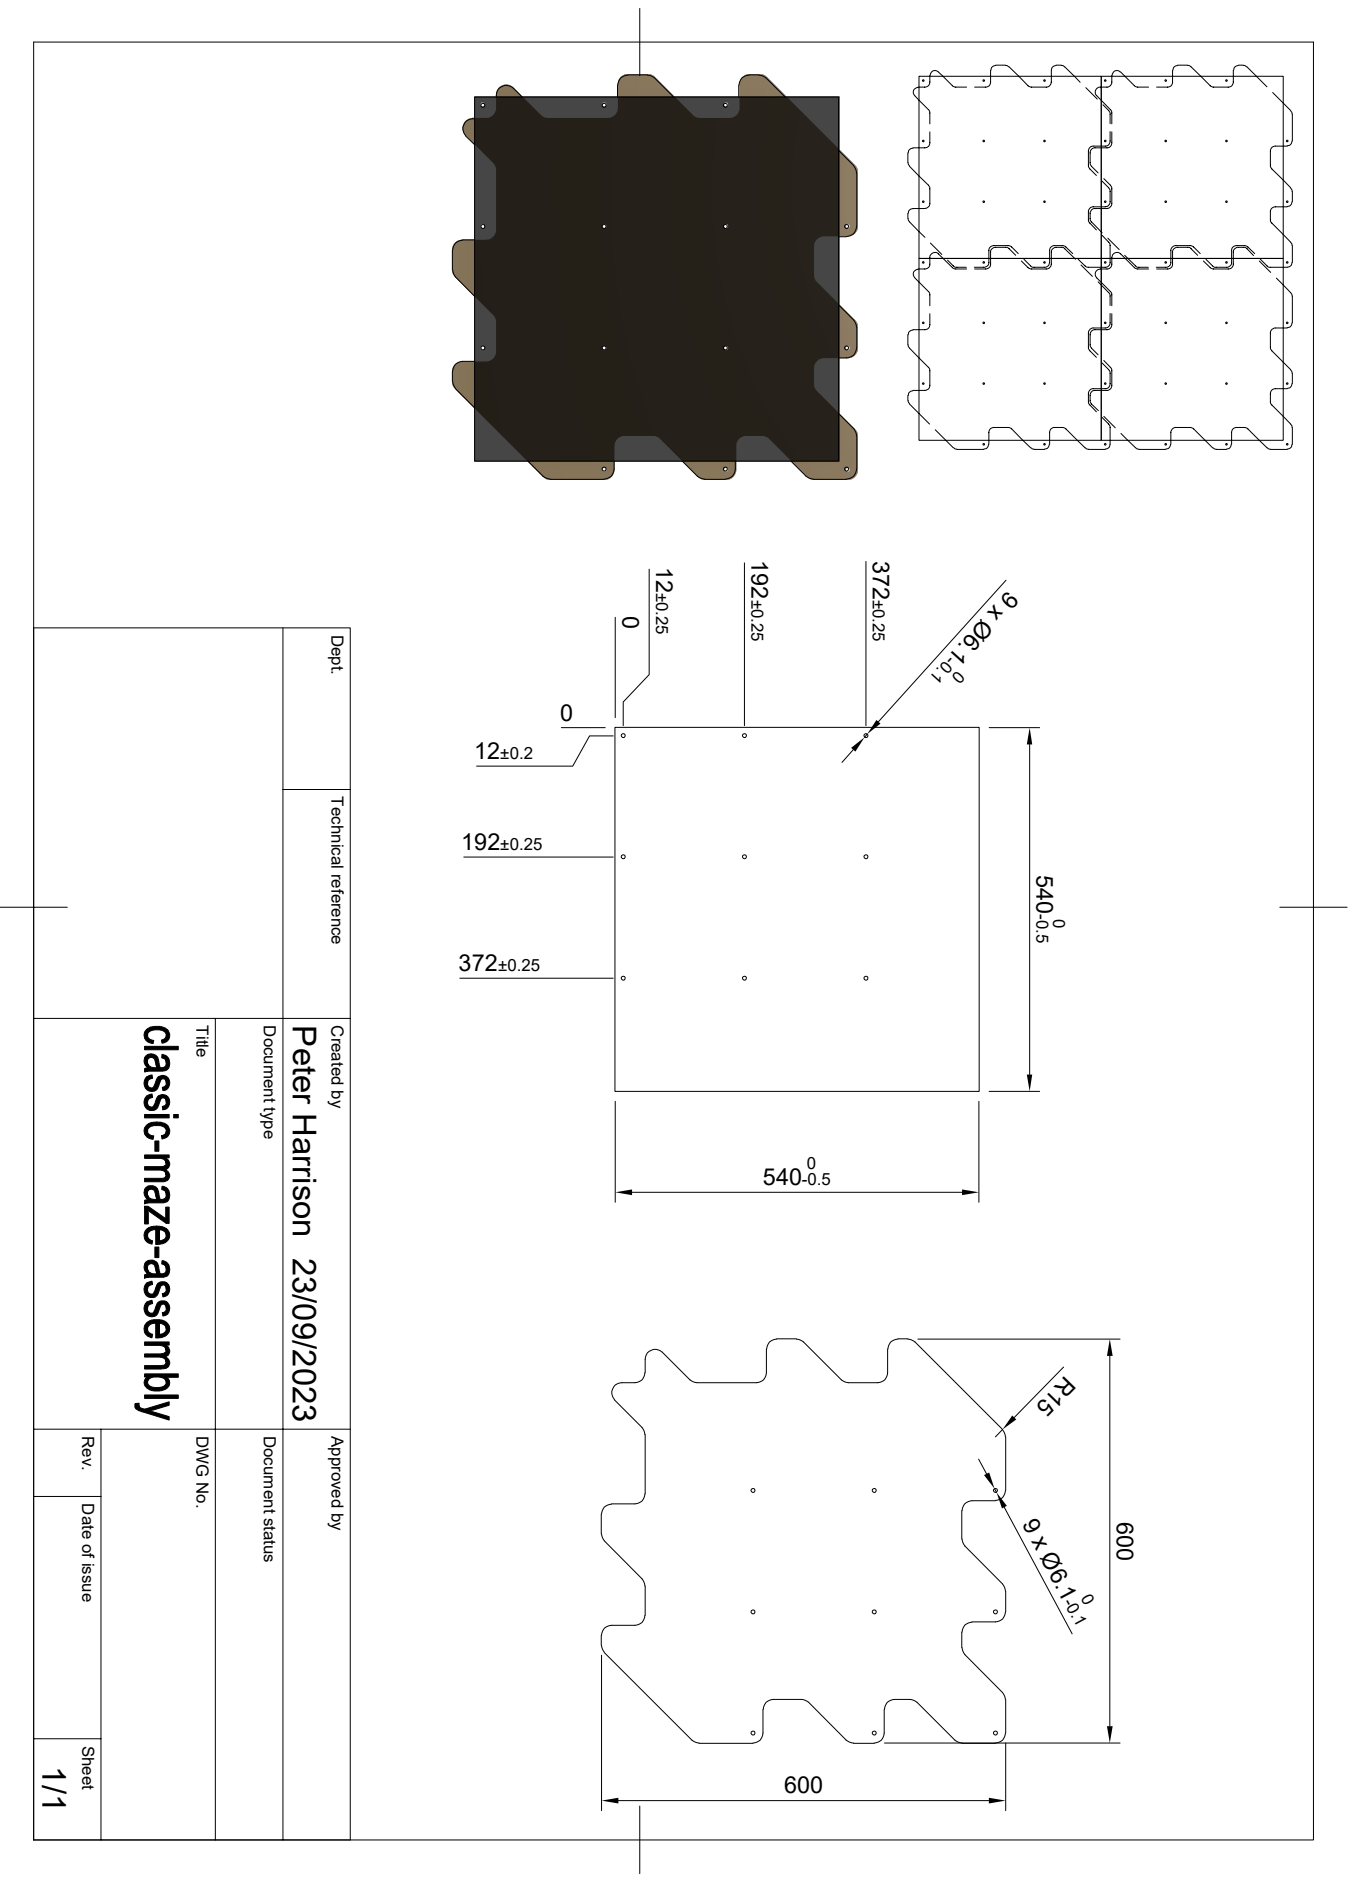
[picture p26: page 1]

Dept. Technical reference Created by Approved by Title DWG No. Document type Document status Rev. Date of issue Sheet 23/09/2023 1/1 Peter Harrison 540 0

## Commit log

2023-02-11 add drawings and images
    [classic-maze-post.STL, classic-tile-360mm.dxf, classic-tile-540mm.dxf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]
2023-02-11 Notes about drilling jigs
2023-02-11 notes on jigs
    [drill-guide-holder.stl]
2023-02-12 update drilling jig reference
2023-02-12 move materials pages
2023-02-12 update links to materials
2023-02-12 move some more files about
    [classic-maze-post.STL, drill-guide-holder.stl]
2023-12-06 add notes on final design
    [classic-maze-tile-540mm-cut2d.dxf]
2024-04-05 new 3D printed wall and post files
    [new-classic-post.stl, new-classic-wall-half-female.stl, new-classic-wall-half-male.stl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]
2024-04-05 update prototype info
2024-04-18 classic post slot size increased to 2.25mm
    [new-classic-post.stl]
2024-04-18 add drawing and cut2d file for 540mm classic maze tiles
    [classic-maze-tile-540mm-cut2d.dxf]
2024-04-20 remove slot fillet
    [new-classic-post.stl]
2024-05-23 add dxf files for new base tiles
    [UKMARS-maze-tile-540mm-bottom.dxf, UKMARS-maze-tile-540mm-top.dxf, old-classic-maze-post.STL]
2024-07-05 Bring up to date with current designs
    [old-classic-maze-post.STL]
2024-10-02 update with 2024 designs and files
    [classic-maze-post-complete-2024.stl, classic-maze-post-half-2024.stl, classic-maze-wall-printed-2024.stl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]
2024-10-03 add a note about glue
2024-10-03 fixup resin printed post
    [classic-maze-post-complete-2024.stl]
2024-10-18 update chamfer on resin printed post
    [classic-maze-post-complete-2024.stl]
